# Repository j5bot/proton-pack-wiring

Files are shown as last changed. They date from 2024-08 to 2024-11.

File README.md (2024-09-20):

# HasLab Spengler Proton Pack / Other Pack Wiring
Diagrams and how-tos for wiring up your proton pack's power and audio

## [12V Power Assembly](power/12V%20Power%20Assembly.md)

With this power assembly, you'll be able to:

- Charge your internal battery from an external charging port
- Isolate your pack electronics when charging your internal battery using a bypass switch
- Via a 12V port, use a secondary power source (external battery) which will be isolated from the
  internal battery using the same bypass switch
- See whether your pack electronics are isolated from your internal battery / charger based on
  an LED indicator being blue
- See whether your pack electronics are getting power from either an internal or external power
  source based on an LED indicator being red

[Document](power/12V%20Power%20Assembly.md)

## [Power Panel Install](panel/Power%20Panel%20Install.md)

Documents installing a power panel which uses the [
12V Power Assembly](power/12V%20Power%20Assembly.md) in the HasLab proton pack snack compartment.

[Document](panel/Power%20Panel%20Install.md)

<!--
### For Users of 5V / 6V Keep-Alives or Pack Electronics

Especially for HasLab pack users, a 12V to 6V step down
converter is recommended rather than using the 5V USB
output from the Talentcell battery.

A separate page will be created for how to add the
step down to this circuit.

- [Part: 12V to 6V step down](https://amzn.to/3XfXYzH)
- [Part: 12V to 5V step down](https://amzn.to/4dYcIIU)

## [Amp Audio with Bypass Switch](amp-audio/Amp%20Audio%20with%20Bypass%20Switch.md)

This mod adds a 30W amplifier,new speaker, and a bypass switch to route around the amplifier.
-->

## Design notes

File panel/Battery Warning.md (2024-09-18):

# Battery Handling Warning

As part of this project, I installed a de-cased 11000mAh Talentcell into my pack.

While working with the battery outside its case (and not in the pack), I carelessly touched contacts on the board which has the switch and ports to contacts on the board which is attached to the battery cells and regulates them.  This burnt out circuitry on the boards and even started a very small fire which luckily was easily extinguished.

I cannot stress enough that although we are careful in our work on our packs that some of the things we do are not without risk.

I do not *recommend* that you follow my example and remove the case of your battery in order to install it in your pack.  You do so at your own risk.

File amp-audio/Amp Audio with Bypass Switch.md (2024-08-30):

# Audio Wiring with Amp Bypass

## Overview

We will be disconnecting the pack audio from the
built in speaker.  Then we will connect the pack
audio to the aux input of a 30W mono amplifier
before routing it to a new higher power speaker.

Along the way, we'll pass the signals through a
bypass switch, allowing the pack audio to be
reconnected directly to the speaker while taking
the amplifier out of the audio circuit.

## Features

- Mono amp
  - App control through phone
  - Aux in
  - Play files from USB
  - Bluetooth audio from phone
- Higher power speaker
- Amp bypass to use original pack audio

## Diagram

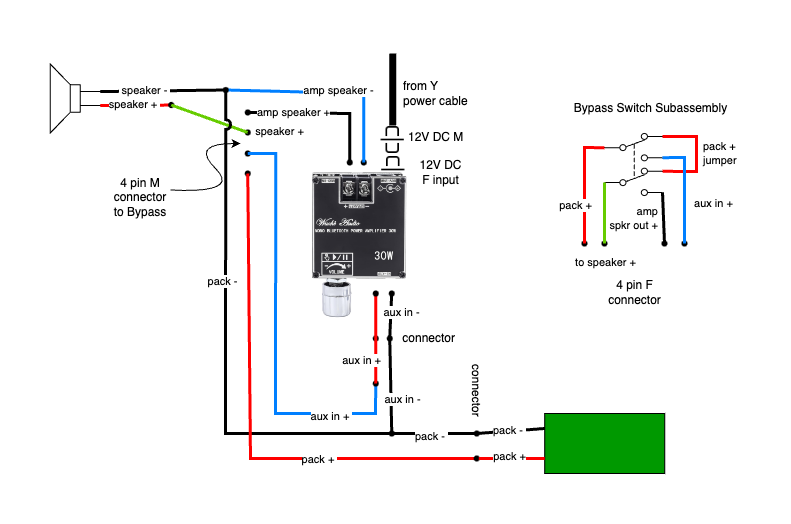
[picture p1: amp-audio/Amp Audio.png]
Amp Audio


([draw.io source](Amp%20Audio.drawio))

## Guide

### Tools

- Wire cutter
- Wire stripper
- Crimper
- Soldering iron and supplies
- Fasteners for mounting the amp
- Drill for mouting the bypass switch

### Parts

1. [Mono amp](https://amzn.to/3Mmv7n8)
2. [3" speaker](https://amzn.to/4cKyq2i)
3. 3.5mm mono (or stereo) "headphone" pre-wired [jack](https://amz.run/9VQ6)
  or [cable](https://amz.run/9VQ9)
4. [1 x DPDT switch](https://amzn.to/3yMudNG) (common for other wiring)
5. [1 x 4 pin connector](https://amzn.to/3Z5QMY5) (common for other wiring)
6. [4 x 2 pin F connector](https://amzn.to/3Mq3lpL) (common for other wiring)
7. [4 x 2 pin M connector](https://amzn.to/3Mq3lpL)
8. [butt connectors (18g)](https://amzn.to/4cEEYiH)

<!--
### Wire List

- AUX 2 pin F
  - red - aux in connector
  - black - aux in connector
- AUX 2 pin M
  - red - bypass connector
  - black - pack audio ground
- PACK 2 pin F
  - red - pack audio
  - black - pack audio
- PACK 2 pin M
  - red - bypass connector
  - black - pack audio ground
- SPKR 2 pin F
  - red - speaker in
  - black - speaker in
- SPKR 2 pin M
  - red/red - bypass connector
  - black - pack audio ground
- AMP 2 pin F
  - red
  - black
- AMP 2 pin M
  - red
  - black
- 4 pin F
- 4 pin M
-->

### Aux In

1. Cut 3.5mm connector cable (if necessary)
2. Connect red/black (and white if stereo) wires wire wire from
   3.5mm connector cable to 2 pin F connector using butt connectors (label AUX)
   
<!--
- AUX 2 pin F red/black
-->

### Pack Audio

1. Cut red/black wires wire wire from pack main board to pack speaker
2. Connect red/black wires wire wire 
   from pack main board to 2 pin F connector using butt connectors (label connector PACK)
   
<!--
- PACK 2 pin F red/black
-->

### Speaker In

1. Connect red/black wires wire wire 
   from 2 pin F connector to the new speaker (label connector SPKR)
   
<!--
- SPKR 2 pin F red/black
-->

### Bypass Switch Connector

1. Connect blue wire wire of 4 pin F connector to red wire wire of
   2 pin M connector (label AUX)
2. Connect red wire wire of 4 pin F connector to red wire wire of
   2 pin M connector (label PACK)
3. Connect green wire wire of 4 pin F connector to red wire 
   wire of 2 pin M connector (label SPKR)
4. Connect black wire wire of 4 pin F connector to red wire
   wire of 2 pin M connector (label AMP)
   
<!--
- 4 pin F blue/red/green/black
- AUX 2 pin M red
- PACK 2 pin M red
- SPKR 2 pin M red
- AMP 2 pin M red
-->

### Bypass Switch Sub-Assembly

2. Solder red wire wire of 4 pin M connector to right center of bypass switch
3. Solder green wire wire of 4 pin M connector to left center of bypass switch
4. Solder a red wire wire jumper of left top of bypass switch to 
   right top of bypass switch
5. Solder blue wire wire of 4 pin M connector to right bottom of bypass switch
6. Solder black wire wire of 4 pin M connector to left bottom of bypass switch
1. Mount bypass switch at desired location

<!--
- 4 pin M red/green/blue/black
-->

### Main Wire Harness

#### Bypass Switch Section
1. Connect a blue wire wire 'jumper' to the black wire wire of a
   2 pin F connector using a butt connector (label AMP)
2. Connect the black wire wire of the 4 pin F connector 
   to the red wire wire of the AMP 2 pin F connector using a butt connector
3. Connect the blue wire wire of the 4 pin F connector to the red wire
   wire of a 2 pin F connector (label AUX)
4. Connect the green wire wire of the 4 pin F connector to the
   red wire wire of a 2 pin M connector (label SPKR)

<!--
- AMP 2 pin F red/black
- SPKR 2 pin M red
-->

#### The Rest
1. Connect the black wire wire of the AUX 2 pin M connector,
   the black wire wire of the PACK 2 pin M connector, and
   a black wire wire 'jumper' using a butt connector
2. Connect the black 'jumper' wire wire from above to the
   black wire wire of the SPKR 2 pin M connector, and the black wire
    wire of the AMP 2 pin M connector using a butt connector
   
<!--
- AUX 2 pin M black
- PACK 2 pin M black
- SPKR 2 pin M black
- AMP 2 pin M black
-->

### Assembling the Circuit

Connect the paired 2 pin M and F connectors

- AUX F to M
- PACK F to M
- SPKR F to M
- AMP F to M

Connect the 4 pin bypass switch connectors

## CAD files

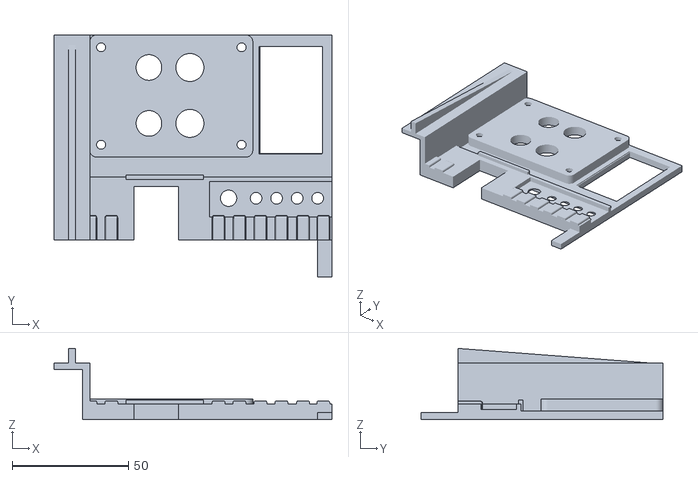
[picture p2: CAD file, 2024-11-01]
panel/Power panel finished (combined).stl
119.3 x 104.0 x 30.5

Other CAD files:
panel/panel.stl

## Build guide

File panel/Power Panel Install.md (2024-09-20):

# Power Panel Install

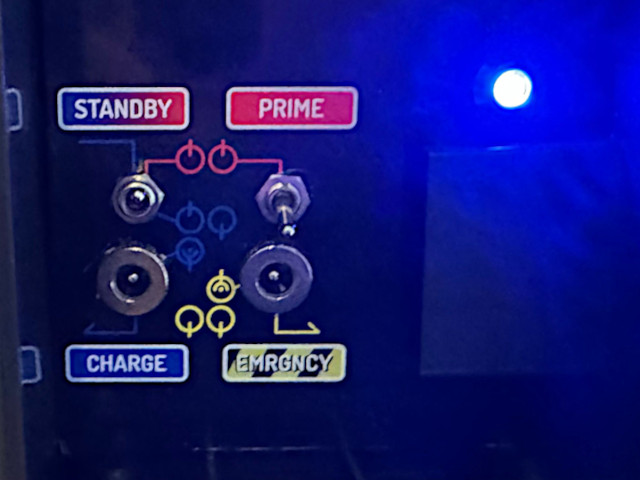
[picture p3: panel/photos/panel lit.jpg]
panel lit.jpg


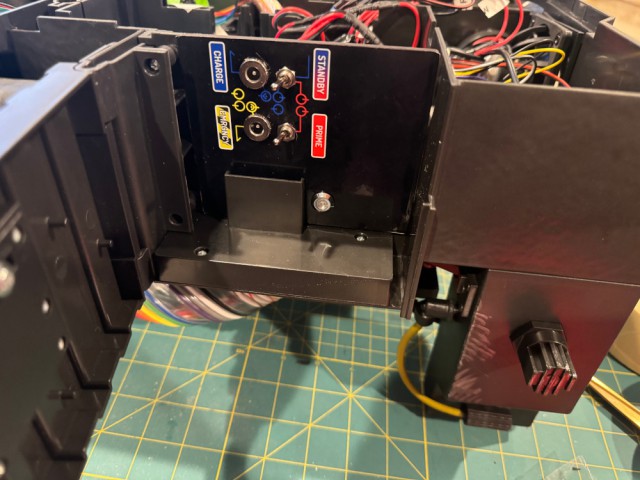
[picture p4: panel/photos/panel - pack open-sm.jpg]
panel - pack open-sm.jpg


This panel uses the [12V Power Assembly](../power/12V%20Power%20Assembly.md) circuit I detail 
elsewhere on this 'site' to provide functionality to charge your pack with electronics isolated, 
run your pack from your internal battery, and to run your pack from an external battery with the 
internal battery isolated.

[Appendix: Possible Additions...](#possible-additions)

You can use it with 5V/6V pack electronics with the addition of a 12V to 6V step down converter.

## Videos

- [Power Panel Demo (Quick)](https://youtube.com/shorts/JSzOQSbEpJE)
- [Power Panel Demo (Long)](https://youtu.be/zHAtCDo_cRU)

## WARNING

**BEFORE PROCEEDING, [READ THIS](Battery%20Warning.md)**

**YOU DID [READ THIS](Battery%20Warning.md), RIGHT?**

## Pack Mods / Cuts

There are several areas you’ll need to cut into the proton pack if installing into the power cell “snack” compartment or a HasLab.

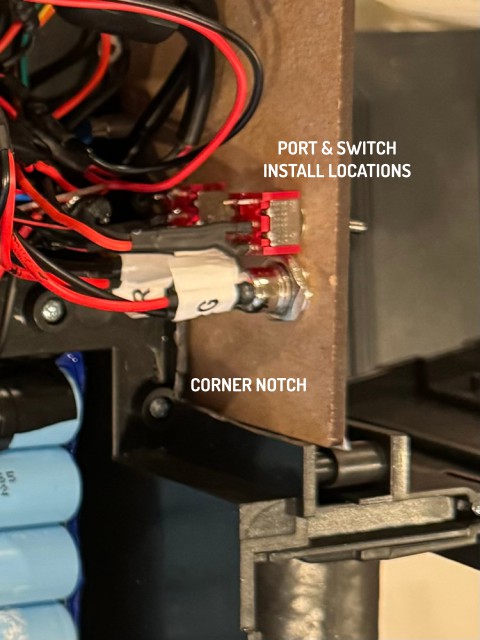
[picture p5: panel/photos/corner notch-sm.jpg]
corner notch.jpg


(Photo 1)

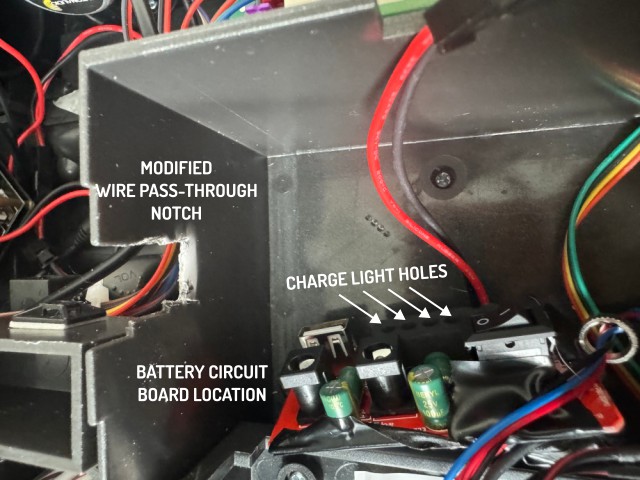
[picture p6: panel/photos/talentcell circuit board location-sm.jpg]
talentcell circuit board location.jpg


(Photo 2)

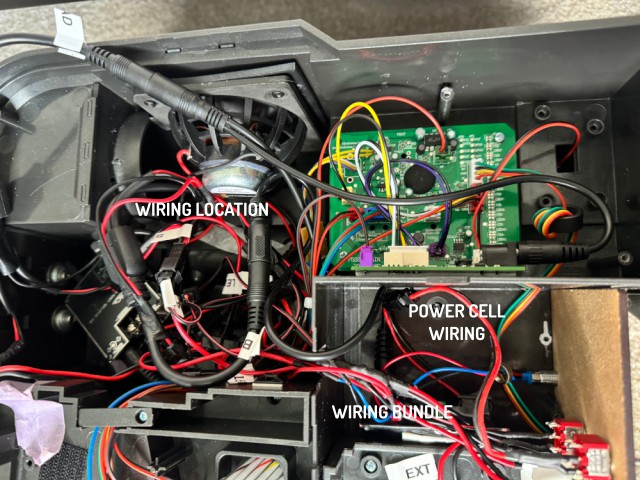
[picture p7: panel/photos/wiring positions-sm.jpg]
wiring positions-sm.jpg


(Photo 3)

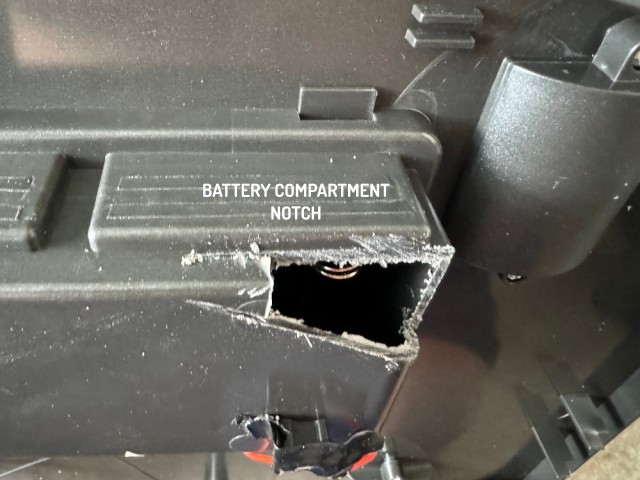
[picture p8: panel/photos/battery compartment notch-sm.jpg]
battery compartment notch.jpg


(Photo 4)

| Area | Image |
|---|---|
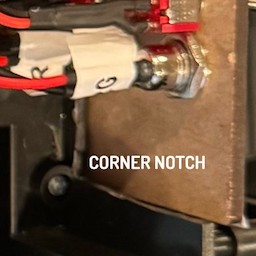
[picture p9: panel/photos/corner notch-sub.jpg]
corner notch-sub.jpg
| First, there is a corner between the booster tube cavity and snack compartment cavity.  Making this cut allows for mounting switches and ports lower on the panel (Photo 1: CORNER NOTCH). |  |
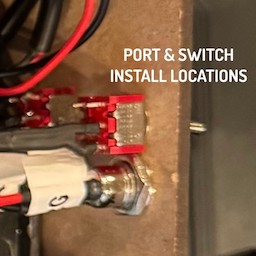
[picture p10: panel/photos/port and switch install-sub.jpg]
port and switch install-sub.jpg
| You can reference the photo to see how far you need to cut to mount the ports in the locations where I did (Photo 1: PORT & SWITCH INSTALL LOCATIONS). |  |
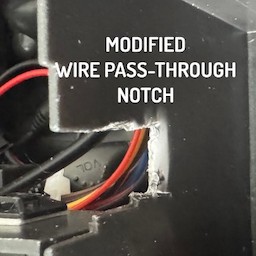
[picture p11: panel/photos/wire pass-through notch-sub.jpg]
wire pass-through notch-sub.jpg
| Secondly, you’ll make the “notch” that the power cell cable normally goes through into the main top cavity deeper, allowing you to pass the power assembly wires through from the snack area into the main body (Photo 2: MODIFIED WIRE PASS-THROUGH NOTCH). |  |
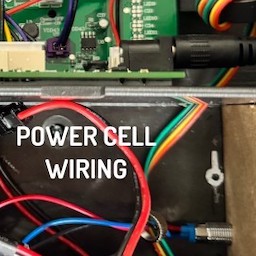
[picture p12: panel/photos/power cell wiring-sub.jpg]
power cell wiring-sub.jpg
| Optionally, in order to provide a clearer space in the snack cavity, you can remove the main board and then carefully cut a small hole between it and the ion arm / right cavity.  Once cut, turn the power cell electronics JST connector sideways, pass it through the hole carefully and plug it back in (Photo 3: POWER CELL WIRING). |  |
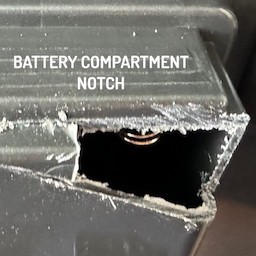
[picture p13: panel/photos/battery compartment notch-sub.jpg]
battery compartment notch-sub.jpg
| Thirdly, you’ll cut a notch out of the bottom of the D Cell battery compartment bottom to clear more room for switches and ports on the panel (Photo 4: BATTERY COMPARTMENT NOTCH). |  |

## Replacement Panel

I chose to use an [
MDF replacement panel from ImperialTechShopUS
](https://www.etsy.com/listing/1415573195/talent-cell-hole-snack-compartment).  It was easy to work with and good 
quality overall but there were minor problems with either it or the pack itself not being square.
Probably the pack.

### Design

I designed a sticker to be placed on the panel, through which holes would be drilled for 
mounting the various components.  I didn't design any graphics or specific placement for the LED 
indicator.

The sticker is taller than it needs to be, on the bottom, because it includes space representing 
the bottom of the 'bump-out' on an original panel.

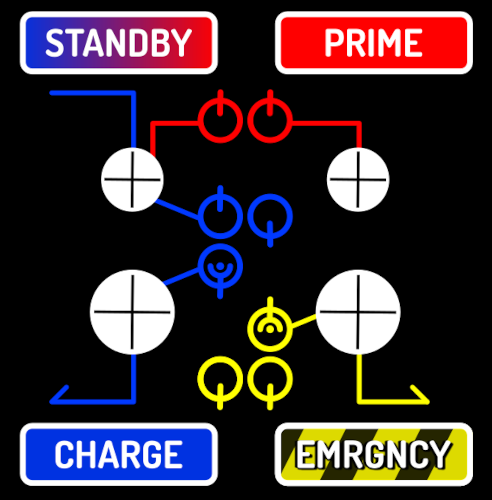
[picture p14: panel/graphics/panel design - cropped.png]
panel design - cropped


[full sticker](graphics/panel%20design.png)

## Standby Switch

The 'STANDBY' switch is a secondary power switch for your internal battery.  In order to have 
one, you'll need to solder onto the contacts which come out of the back of the battery's circuit 
board where the primary switch is located.

**YOU DID [READ THIS](Battery%20Warning.md), RIGHT?**

I don't have any instructions on this at the moment.  When you solder onto it, you'll add a 
quick connect.  The other side of the quick connect will plug into the actual switch.

## Mounting Holes

Center punch or otherwise mark the holes you'll be drilling by pressing through the 'crosshairs' 
in the design.  Then, carefully cut out the guide circles with something like a craft knife / 
x-acto.

This will help get a nice clean hole through the sticker and a properly aligned drill.

Be careful with where you drill your LED indicator hole, since I didn't mark it and the 
placement is a bit tricky.

## Quick Connect Modifications

The MALE quick connects on the ports and LED are going to have to go through the holes you drill 
in the panel.

For the ports, in order to do so, the portion of the quick connect which sticks out from the main 
body at angles will have to be snipped off.

For the LED indicator, the tabs at the end of the quick connects (not the one on the top!) will 
also need to be snipped off.  The image below shows one side, but there are tabs on the hidden 
side, too.

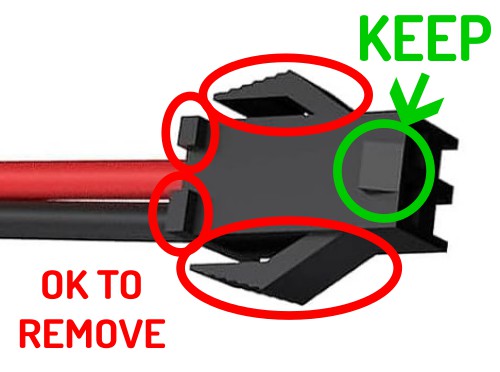
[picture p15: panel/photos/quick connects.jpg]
quick connects.jpg


## Assembly

1. Run the wiring through the holes in the panel for your ports and LED indicator.  Snip off 
   bits of the quick connects as needed to get everything through.

   You may need to omit the LED indicator 'nut' if your indicator sits close to the pack 
   internals1 or you can't get it over the quick connects and wires at the same time.  You can always use something like electrical tape or a rubber band to hold it in a little bit more.  Experiment.
2. Run the two switches through the holes from the back side of the panel.  Don't connect the 
   main power switch yet.
3. Test fit your panel and make sure that everything seems ok.

### Bench Testing the Circuit (No Pack Electronics)

This portion may have done previously, but it's a good idea to do it again, regardless.

1. Remove the panel and assemble the wiring by connecting the quick connects, but don't connect to 
   batteries or pack electronics yet.
2. Make sure that the 'PRIME' switch is flipped down and plug an external battery source 
   (this can be your internal battery if needed) into the yellow 'EMRGNCY' port.  Turn on the 
   battery and you should get a red indicator.  If you don't get that, you'll have to 
   troubleshoot the 'LOAD' side of your circuit.
3. Turn off and disconnect the battery from the 'EMRGNCY' port.
4. Connect the battery to the 'BATT' side 12V plug.  Turn the battery on using the built-in 
   switch.  You should see the blue indicator.  If you don't you'll have to trouble-shoot the 
   'BATT' side of the circuit.
5. Flip the 'PRIME' switch on.  You should now see the indicator turn red.
6. Flip the 'PRIME' switch off.  You should see the blue indicator light. Turn the battery off.  You 
   should see no indicator lights.

### Bench Testing the Circuit (Pack Electronics)

1. Connect the pack electronics to the 12V 'LOAD' side plug.  For HasLab packs, make sure that 
   the cyclotron cover is seated well and won't disconnect during the tests.
2. Turn the battery on.  You should see the blue indicator and should NOT be able to power up 
   the pack.
3. Flip the 'PRIME' switch.  You should see the indicator light change to red.
4. Turn the pack on and everything should power up properly.
5. Turn the pack off (NOT with the battery switch or by flipping 'PRIME'!)
6. Flip down the 'PRIME' switch.  The indicator should turn blue.
7. Turn off the battery.  The indicator light should turn off.
8. Plug a battery into the 'EMRGNCY' port.  Turn the battery on.  The indicator should turn red.
9. Turn the pack on and everything should power up properly.
10. Turn the pack off (NOT with the battery switch!)
11. Turn the battery off and disconnect it from the port.

### Pack Installation

1. Disconnect the 'BATT' 12V, 'LOAD' 12V, and anything else you may have plugged in that isn't 
   part of the circuit wiring.
2. Install the panel in the snack compartment.
3. Connect the internal battery's secondary switch which you added to the 'STANDBY' switch quick 
   connect.
4. Route the rest of your wiring where it makes the most sense to you.  Don't try to do any 
   cable management yet, as you may need to troubleshoot something.
5. Connect the internal battery to the circuit with the 'BATT' side 12V plug.
6. Check that flipping the 'STANDBY' switch lights up the blue indicator.
7. Flip the switch back off.
8. Connect the 'LOAD' 12V plug to your pack electronics.

Now run through the same sequence as 'Bench Testing the Circuit (Pack Electronics)' as above in 
order to test that everything in the circuit is functioning with the way you've installed it.

1. Test fit the motherboard without closing the pack up.  If it doesn't sit properly, troubleshoot 
why it doesn't.
2. Do any cable / wire management tasks that you want to do.
3. Repeat some basic testing if you'd like.
4. Close up your motherboard.

Test the functionality out again ... and enjoy your new power panel!

## Appendix: Possible Additions

Using this [fiber optic tubing](https://amz.run/9apS) and additional holes drilled
for mounting the ends, you can add the ability to see the battery charge level to the panel.  
Connect the tubing to the charge light holes (Photo 2: CHARGE LIGHT HOLES).

Add a port to charge USB devices by connecting one of [
these USB panel mount ports](https://amz.run/9apU) to a [
USB bare wire pigtail](https://amz.run/9apW) using quick connects.

Add voltmeters, ammeters, etc.

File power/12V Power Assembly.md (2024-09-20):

# 12V Power Assembly Wiring

## Features

With this power assembly, you'll be able to:

- Charge your internal battery from an external charging port
- Isolate your pack electronics when charging your internal battery using a bypass switch
- Via a 12V port, use a secondary power source (external battery) which will be isolated from the 
  internal battery using the same bypass switch
- See whether your pack electronics are isolated from your internal battery / charger based on
  an LED indicator being blue
- See whether your pack electronics are getting power from either an internal or external power
  source based on an LED indicator being red

### 5V / 6V Powered Electronics

If you are using 5V (USB) or 6V electronics, the best way to utilize this circuit is by adding a 
12V to 6V stepdown between the LOAD connector and the pack electronics.

A document on how to do so is forthcoming.  In the meantime, know that you should use something 
like [this 12V to 6V step-down converter](https://amz.run/9anl).

### Videos

[Overview (1:56)](https://youtu.be/uO9-Ru0Y7kw)

[Longer Explanation (3:43)](https://youtu.be/x2D-j18WvII)

[Deeper Dive (6:40)](https://youtu.be/GxCZtZ-E1Ig)

## Overview

For this project we will create two identical
Y connectors with 12V DC input, 12V DC output and
connect them together with a bypass switch and LED indicator.

## Photos

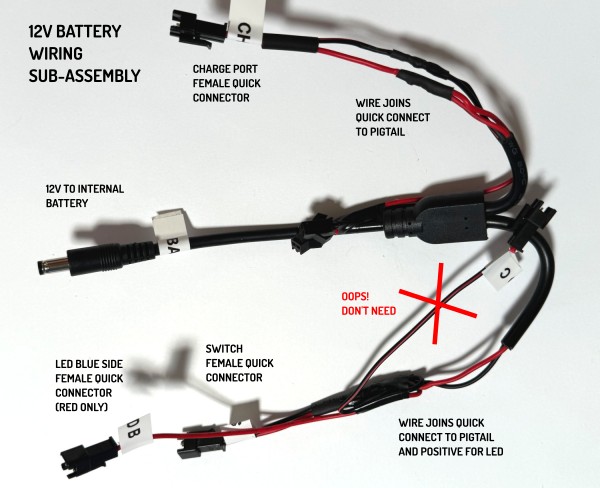
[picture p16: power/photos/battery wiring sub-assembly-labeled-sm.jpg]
battery wiring sub-assembly-labeled.jpg


Battery-side wiring Y sub-assembly

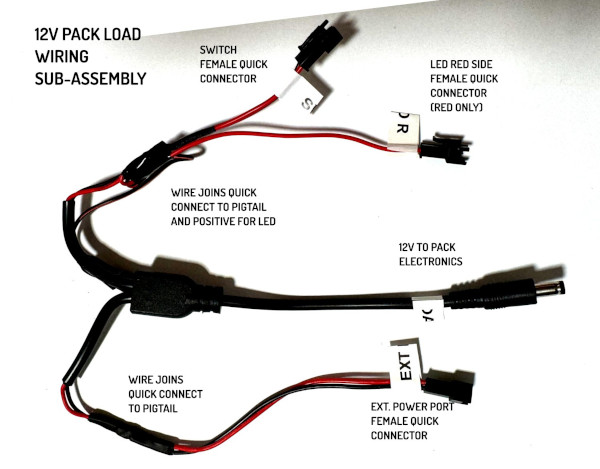
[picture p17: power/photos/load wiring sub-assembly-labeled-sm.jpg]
load wiring sub-assembly-labeled.jpg


Load-side wiring Y sub-assembly

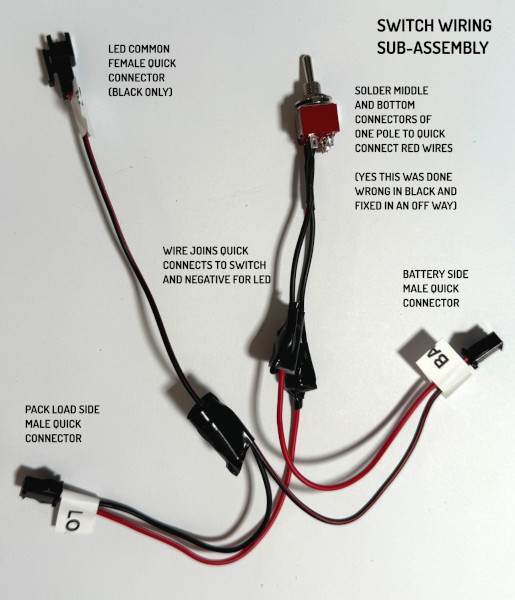
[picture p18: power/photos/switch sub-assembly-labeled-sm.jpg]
switch sub-assembly-labeled.jpg


Switch wiring sub-assembly

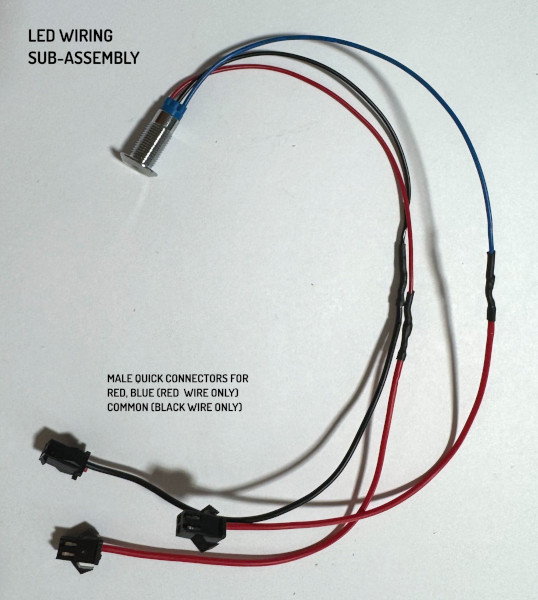
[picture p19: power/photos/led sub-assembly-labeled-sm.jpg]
led sub-assembly-labeled.jpg


Two-color LED indicator sub-assembly

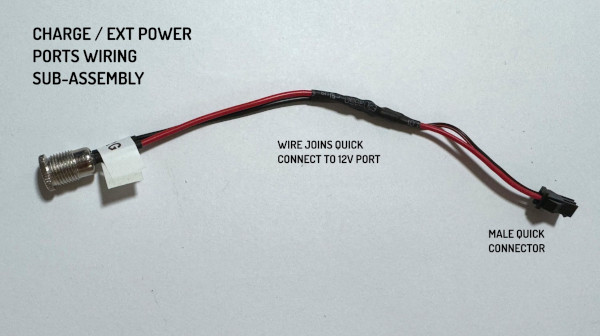
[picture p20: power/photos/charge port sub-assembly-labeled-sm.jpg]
charge port sub-assembly-labeled.jpg


Charge & External power sub-assemblies

## Diagram

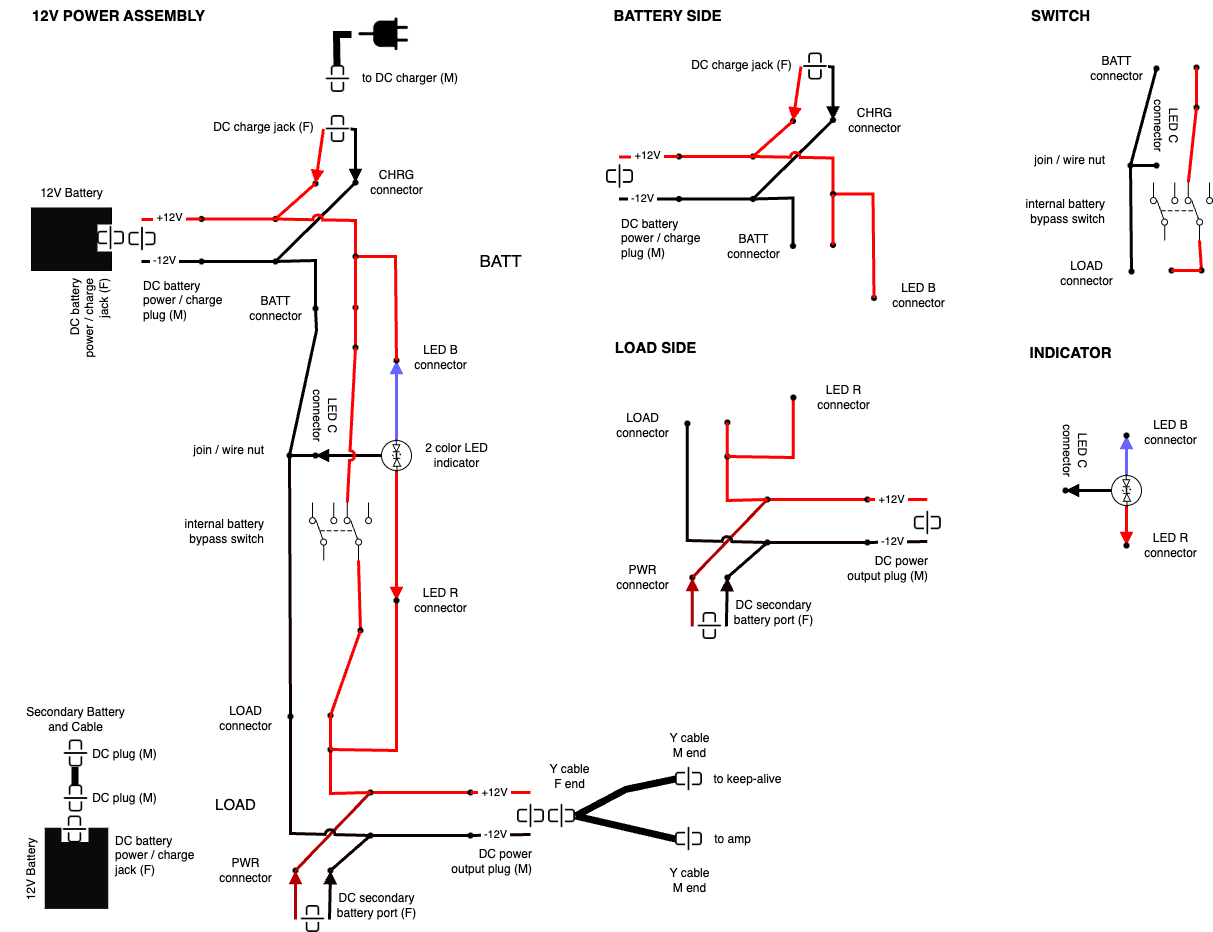
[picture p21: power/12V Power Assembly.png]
12V Power Assembly Wiring Diagram


([draw.io source](12V%20Power%20Assembly%20-%20With&20Indicator.drawio))

## Guide

### Tools

1. Soldering iron and supplies to wire disconnect switch to quick connect wires

### Parts

1. [2 x 12V DC rechargeable battery pack (6000mAh)](https://amzn.to/4dzqkdP)
2. [2 x 12V DC M plug to 2 pigtail (18g)](https://amzn.to/4fVek8b)
3. [1 x 12V DC M to M cable, 3ft (18g)](https://amzn.to/4dRkZit)
4. [7 x F connector (pre-wired red/black, 18g)](https://amzn.to/4e0jmyx)
5. [7 x M connector (pre-wired red/black, 18g)](https://amzn.to/4e0jmyx)
6. [2 x DC barrel jack (pre-wired red/black, 18g)](https://amzn.to/4dRy4ri)
7. [1 x DPDT mini toggle switch](https://amzn.to/471Q0gT) 
   or [pre-wired SPST toggle switch](https://amzn.to/3Zr1RU2) for no-solder option
   (doesn't actually need DPDT ... can substitute SPST)
8. [butt connectors (18g)](https://amzn.to/4cEEYiH), [wire nuts](https://amz.run/9Xn1) or opt 
   for soldered wire connections
9. cable and wire management supplies ([zip ties](https://amz.run/9Xnz), 
   [zip tie mounts](https://amz.run/9XnW)) as desired
10. [1 x 12V Y-Cable -- 1F to 2M ends](https://amzn.to/3MgKJsl) (if needed for split load such
    as 12V keep-alive and amp -- also included with Talentcell battery pack, so optional)
11. [0-# x 12V extension cables](https://amzn.to/3MjNKYL) (0 or more, depending on mounting 
   locations)

## Power Sub-Assemblies

### Battery Connection Sub-Assembly

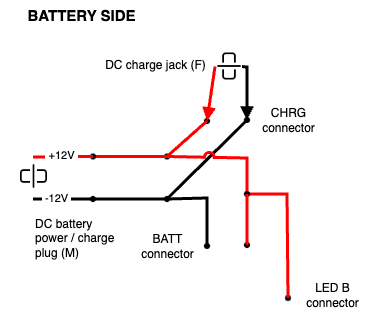
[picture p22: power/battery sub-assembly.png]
battery sub-assembly.png


battery wiring sub-assembly-labeled-sm.jpg

1. Label one 12V pigtail (part #2) BATT
2. Connect one bare-wire side of a 12V pigtail to a pre-wired FEMALE quick connector 
   (part #4)
   using your preferred wire connection strategy.  Label the two-wire quick connector CHRG.
3. Snip the black wire off of one FEMALE quick connector.  Label the connector LED B.
4. Connect the other bare-wire side of the 12V pigtail to both a new pre-wired FEMALE quick 
   connector AND the single-wire connector created in the previous step.  Connect the three red wires to 
   each other and the two black wires to each other.  Label the two-wire FEMALE quick connector BATT SW.

### Pack Load Sub-Assembly

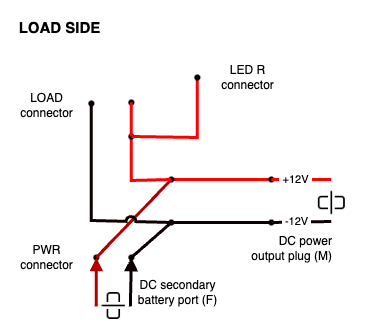
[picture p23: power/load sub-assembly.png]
load sub-assembly.png


load wiring sub-assembly-labeled-sm.jpg

1. Label one 12V pigtail (part #2) LOAD
2. Connect one bare-wire side of the 12V pigtail to a pre-wired FEMALE quick connector
   (part #4)
   using your preferred wire connection strategy.  Label the two-wire quick connector EXT.
3. Snip the black wire off of one FEMALE quick connector.  Label the connector LED R.
4. Connect the other bare-wire side of the 12V pigtail to both a new pre-wired FEMALE quick
   connector AND the single-wire connector created in the previous step.  Connect the three red wires to
   each other and the two black wires to each other.  Label the two-wire FEMALE quick connector 
   LOAD SW.

### Bypass Switch Sub-Assembly

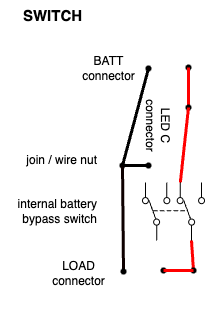
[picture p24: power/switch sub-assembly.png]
switch sub-assembly.png


switch sub-assembly-labeled-sm.jpg

1. Label a MALE quick connector BATT
2. Label a MALE quick connector LOAD
3. Snip the red wire off of one FEMALE quick connector and label it LED
4. Solder the red wire from the BATT connector onto the left center terminal of the DPDT switch
5. Solder the red wire from the LOAD connector onto the left bottom terminal of the DPDT switch
6. Connect the three black wires from BATT, LOAD, and LED quick connectors using your preferred 
   wire connection strategy

### LED Indicator Sub-Assembly

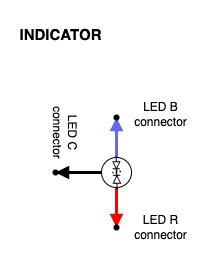
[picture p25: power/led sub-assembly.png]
led sub-assembly.png


led sub-assembly-labeled-sm.jpg

1. Snip the black wires off of two MALE quick connectors, labeling the red wire of one LED B and 
   the red wire of the other LED R
2. Snip the red wire off of one MALE quick connector.  Label the black wire LED C
3. Connect the red wire of the LED to the LED R quick connector red wire
4. Connect the blue wire of the LED to the LED B quick connector red wire
5. Connect the black wire of the LED to the LED C quick connector black wire

### Power Input Sub-Assemblies

charge port sub-assembly-labeled-sm.jpg

1. Connect the black and red wires from one pre-wired 12V port to the black and red wires on one 
   MALE quick connector.  Label it CHRG.
2. Connect the black and red wires from one pre-wired 12V port to the black and red wires on one
   MALE quick connector.  Label it EXT.

### Mounting Assemblies

1. After drilling your mounting holes, you should be able to feed the MALE connectors on the LED 
sub-assembly and the power input sub-assemblies through their respective mounting holes
2. Pass the shaft of your bypass switch through the hole and use the 
washers, nut, etc. to affix the switch and attached sub-assembly

## Connecting Sub-Assemblies

Using your quick connects and matching labels:

1. Connect the CHRG MALE quick connector on the power in sub-assembly to the CHRG FEMALE quick 
   connector on the BATT sub-assembly
2. Connect the EXT MALE quick connector on the power in sub-assembly to the EXT FEMALE quick 
   connector on the LOAD sub-assembly

1. Connect the BATT MALE quick connector on the SWITCH sub-assembly to the BATT SW FEMALE 
   connector on the BATT sub-assembly
2. Connect the LOAD MALE quick connector on the SWITCH sub-assembly to the LOAD SW FEMALE 
   connector on the LOAD sub-assembly

1. Connect the LED B FEMALE quick connector on the BATT sub-assembly to the LED B MALE connector 
   on the LED sub-assembly
2. Connect the LED R FEMALE quick connector on the LOAD sub-assembly to the LED R MALE connector 
   on the LED sub-assembly
3. Connect the LED C FEMALE quick connector on the SWITCH sub-assembly to the LED C MALE 
   connector on the LED assembly

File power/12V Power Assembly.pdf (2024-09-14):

Charging port for primary internal battery
Bypass switch to isolate the pack electronics from the battery while charging
Secondary battery port - just flip the bypass switch and then plug in your emergency power

For this project we will create two identical Y connectors with 12V DC input, 12V DC output and connect them together with a bypass switch.

# 12V Power Assembly Wiring

# Features

# Overview

# Photos

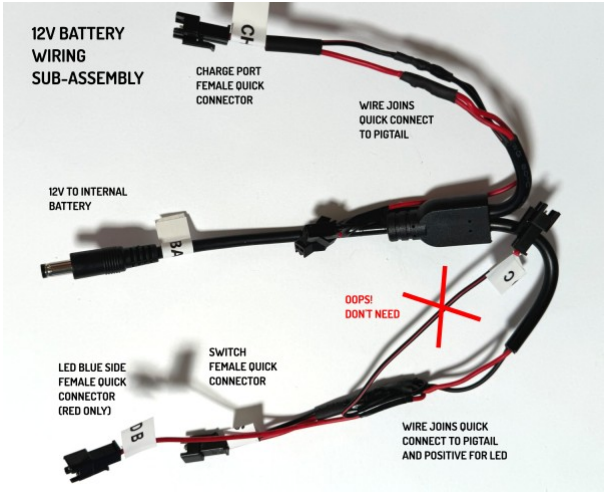
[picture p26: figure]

Battery-side wiring Y sub-assembly


Load-side wiring Y sub-assembly


Switch wiring sub-assembly


Two-color LED indicator sub-assembly


Charge & External power sub-assemblies

# Diagram

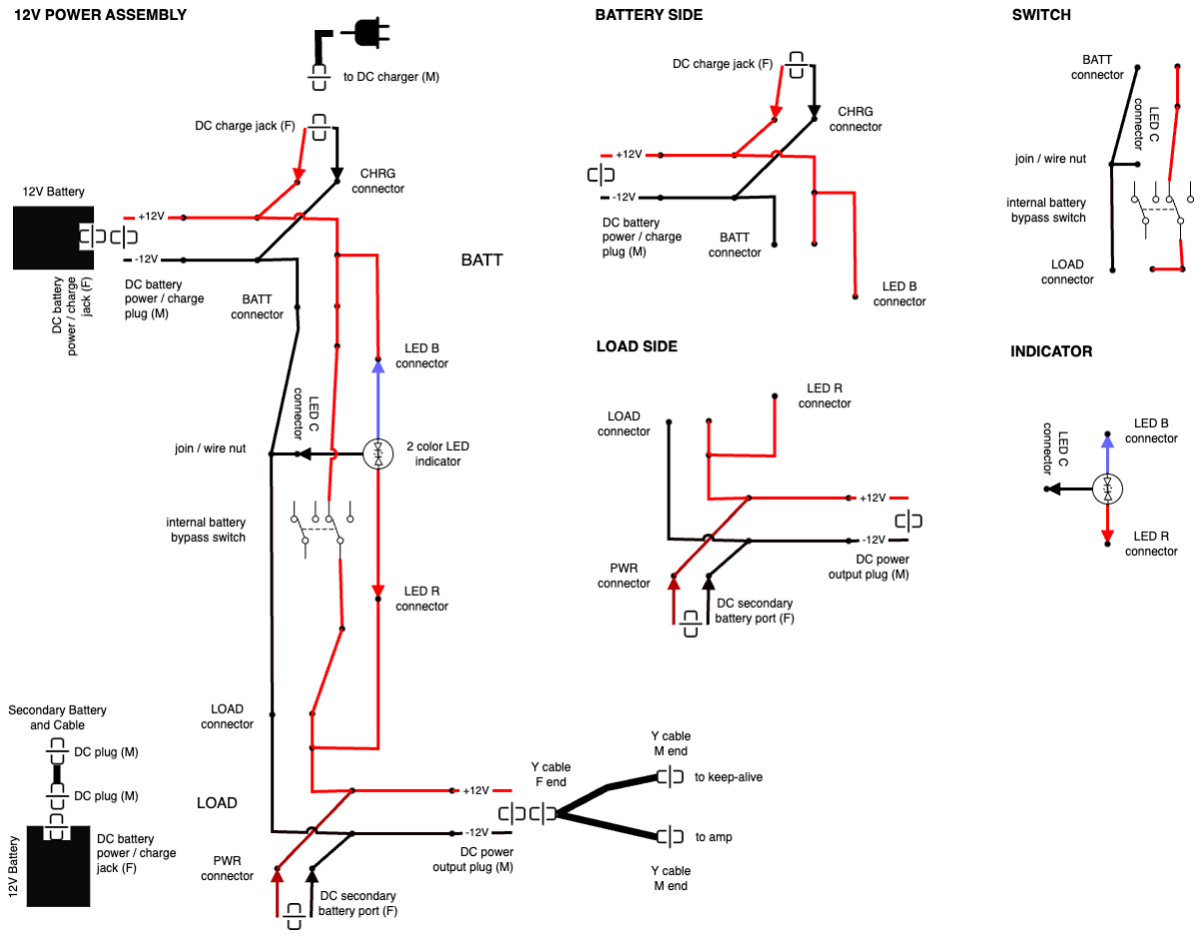
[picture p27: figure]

(draw.io source)

1. Soldering iron and supplies to wire disconnect switch to quick connect wires
1. 2 x 12V DC rechargeable battery pack (6000mAh) (https://amzn.to/4dzqkdP)
2. 2 x 12V DC M plug to 2 pigtail (18g) (https://amzn.to/4fVek8b)
3. 1 x 12V DC M to M cable, 3ft (18g) (https://amzn.to/4dRkZit)
4. 7 x F connector (pre-wired red/black, 18g) (https://amzn.to/4e0jmyx)
5. 7 x M connector (pre-wired red/black, 18g) (https://amzn.to/4e0jmyx)
6. 2 x DC barrel jack (pre-wired red/black, 18g) (https://amzn.to/4dRy4ri)
7. 1 x DPDT mini toggle switch (https://amzn.to/471Q0gT) or pre-wired SPST toggle switch (https://amzn.to/3Zr1RU2) for no-solder option

# Guide

## Tools

## Parts

8. butt connectors (18g), (https://amzn.to/4cEEYiH) wire nuts (https://amz.run/9Xn1) or opt for soldered wire connections
9. cable and wire management supplies (zip ties, (https://amz.run/9Xnz) zip tie mounts) (https://amz.run/9XnW) as desired
10. 1 x 12V Y-Cable -- 1F to 2M ends (https://amzn.to/3MgKJsl) (if needed for split load such as 12V keep-alive and amp -- also included with Talentcell battery pack, so optional)
11. 0-# x 12V extension cables (https://amzn.to/3MjNKYL) (0 or more, depending on mounting locations)

# Power Sub-Assemblies

## Battery Connection Sub-Assembly

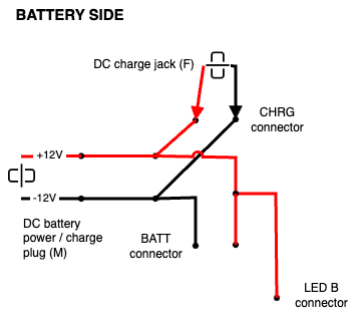
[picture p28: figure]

1. Label one 12V pigtail (part #2) BATT
2. Connect one bare-wire side of a 12V pigtail to a pre-wired FEMALE quick connector (part #4) using your preferred wire connection strategy. Label the two-wire quick connector CHRG.
3. Snip the black wire off of one FEMALE quick connector. Label the connector LED B.
4. Connect the other bare-wire side of the 12V pigtail to both a new pre-wired FEMALE quick connector AND the single-wire connector created in the previous step. Connect the three red wires to each other and the two black wires to each other. Label the two-wire FEMALE quick connector BATT SW.

## Pack Load Sub-Assembly

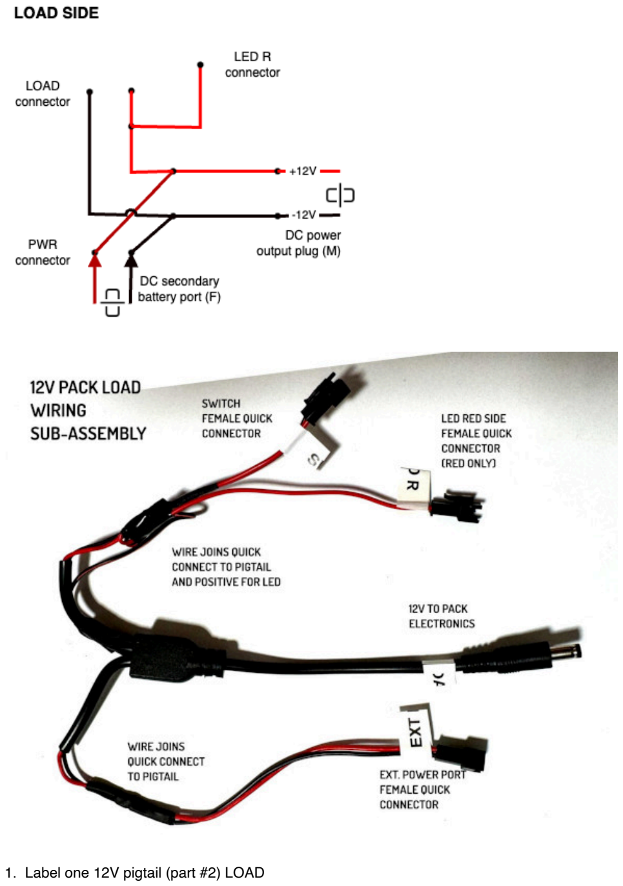
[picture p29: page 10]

1. Label one 12V pigtail (part #2) LOAD

2. Connect one bare-wire side of the 12V pigtail to a pre-wired FEMALE quick connector (part #4) using your preferred wire connection strategy. Label the two-wire quick connector EXT.
3. Snip the black wire off of one FEMALE quick connector. Label the connector LED R.
4. Connect the other bare-wire side of the 12V pigtail to both a new pre-wired FEMALE quick connector AND the single-wire connector created in the previous step. Connect the three red wires to each other and the two black wires to each other. Label the two-wire FEMALE quick connector LOAD SW.

## Bypass Switch Sub-Assembly

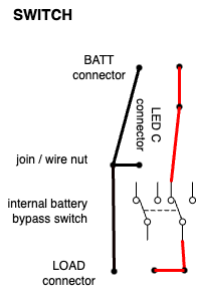
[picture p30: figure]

1. Label a MALE quick connector BATT
2. Label a MALE quick connector LOAD
3. Snip the red wire off of one FEMALE quick connector and label it LED
4. Solder the red wire from the BATT connector onto the left center terminal of the DPDT switch
5. Solder the red wire from the LOAD connector onto the left bottom terminal of the DPDT switch
6. Connect the three black wires from BATT, LOAD, and LED quick connectors using your preferred wire connection strategy

## LED Indicator Sub-Assembly

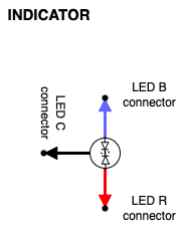
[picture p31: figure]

1. Snip the black wires off of two MALE quick connectors, labeling the red wire of one LED B and the red wire of the other LED R
2. Snip the red wire off of one MALE quick connector. Label the black wire LED C
3. Connect the red wire of the LED to the LED R quick connector red wire
4. Connect the blue wire of the LED to the LED B quick connector red wire
5. Connect the black wire of the LED to the LED C quick connector black wire

## Power Input Sub-Assemblies

1. Connect the black and red wires from one pre-wired 12V port to the black and red wires on one MALE quick connector. Label it CHRG.
2. Connect the black and red wires from one pre-wired 12V port to the black and red wires on one MALE quick connector. Label it EXT.
1. After drilling your mounting holes, you should be able to feed the MALE connectors on the LED sub-assembly and the power input sub-assemblies through their respective mounting holes
2. Pass the shaft of your bypass switch through the hole and use the washers, nut, etc. to affix the switch and attached sub-assembly

Using your quick connects and matching labels:

1. Connect the CHRG MALE quick connector on the power in sub-assembly to the CHRG FEMALE quick connector on the BATT sub-assembly
2. Connect the EXT MALE quick connector on the power in sub-assembly to the EXT FEMALE quick connector on the LOAD sub-assembly
3. Connect the BATT MALE quick connector on the SWITCH sub-assembly to the BATT SW

## Mounting Assemblies

# Connecting Sub-Assemblies

FEMALE connector on the BATT sub-assembly

4. Connect the LOAD MALE quick connector on the SWITCH sub-assembly to the LOAD SW FEMALE connector on the LOAD sub-assembly
5. Connect the LED B FEMALE quick connector on the BATT sub-assembly to the LED B MALE connector on the LED sub-assembly
6. Connect the LED R FEMALE quick connector on the LOAD sub-assembly to the LED R MALE connector on the LED sub-assembly
7. Connect the LED C FEMALE quick connector on the SWITCH sub-assembly to the LED C MALE connector on the LED assembly

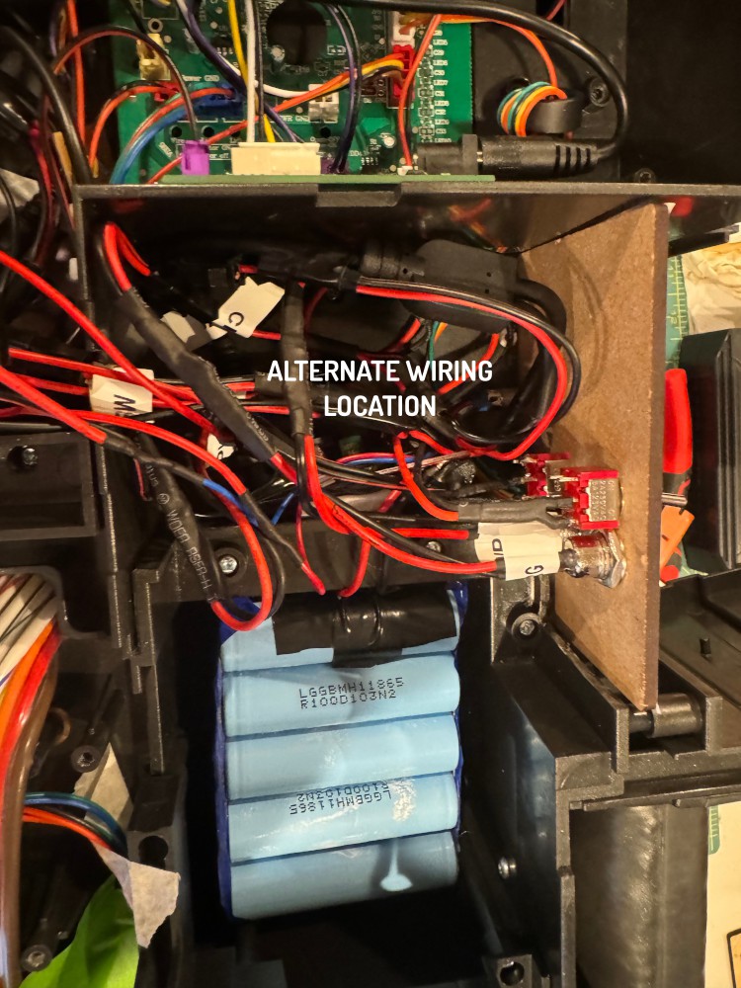
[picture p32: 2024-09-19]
panel/photos/original wiring location.jpg

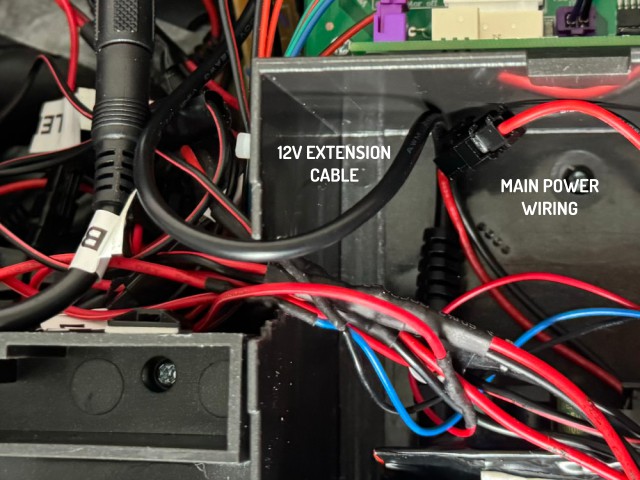
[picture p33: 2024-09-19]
panel/photos/wiring notch-sm.jpg

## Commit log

2024-08-24 power assembly page / diagrams
2024-08-24 Update 12V Power Assembly.md to add links
2024-08-24 Update 12V Power Assembly.md with more links
2024-08-24 Update 12V Power Assembly.md with links
2024-08-24 Update 12V Power Assembly.md ad switch to parts list
2024-08-24 Update 12V Power Assembly.md add m to m cable
2024-08-24 Update 12V Power Assembly.md part numbers
2024-08-24 Update 12V Power Assembly.md part number
2024-08-24 Update Audio Wiring.md
2024-08-25 Update 12V Power Assembly.md add features info
2024-08-25 Update 12V Power Assembly.md add info on 6V step down
2024-08-25 Update 12V Power Assembly.md remove step down
2024-08-26 fixed bypass switch wiring
2024-08-27 change wire color style to images
2024-08-27 update audio wiring diagram and guide
2024-08-27 added wire tracking as progressing on guide
2024-08-29 Update 12V Power Assembly.md with overview
2024-08-30 Update Audio Wiring.md parts list links
2024-08-30 Update Audio Wiring.md bypass switch mount
2024-09-11 add power wiring with indicator
2024-09-12 updated power wiring diagram, add photos of assembled wiring
2024-09-12 added directional arrows for 'M' connector symbol
2024-09-13 Update 12V Power Assembly.md parts list
2024-09-14 revamped after actual construction of circuit
2024-09-14 Update 12V Power Assembly.md
    Add link to pre-wired SPST switches
2024-09-14 updated battery sub assembly labeled photos
2024-09-14 added links to larger sub-assembly images
2024-09-18 power panel install start
2024-09-19 power panel install doc and photos
2024-09-20 power panel install doc finish
2024-09-20 standby switch mention
2024-09-20 link to assembly doc
2024-09-20 move video links to power assembly page
2024-09-20 add link to 12v to 6v stepdown
2024-09-20 add note that SPST switch is ok for power assembly
